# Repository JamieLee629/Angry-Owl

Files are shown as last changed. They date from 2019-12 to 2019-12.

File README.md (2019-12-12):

# Angry-Owl
ECE4180 Fall 2019 Final Project, Georgia Institute of Technology\
Project Members: Jamie Lee, Jingyi Yu

## Summary
A motion-detecting owl scarecrow controlled by a Raspberry Pi 3 Model B. Can move forwards and backwards, rotate, make scary sounds (optional), flap wings, and shine bright lights in the presence of live garden pests such as rodents and deer. The purpose is to scare away these pests which eat the leaves, fruits and vegetables of garden crops.

## Background Information
My dad maintains a large garden, but pests like raccoons and deer will often eat the fruits of his labor. He has tried store-bought deer repellent, but it did not work. It would be useful for gardeners if there was an infrared-detecting scarecrow that can move when it detects a sudden change in infrared radiation levels (i.e. an animal coming into view). Optionally, the scarecrow can make customizable sounds that can [scare the animals away](https://www.thestar.com/news/insight/2016/03/07/the-sound-that-strikes-fear-into-a-raccoons-heart.html). We decided to build our scarecrow in the form of an angry owl. The owl is a common predator among smaller pests, so the form of its silhouette alone can intimidate them. The loud commotion that the angry owl generates serves to scare off larger pests, such as deer and foxes.

## Electronics Parts List:
- 1x [Raspberry Pi 3 Model B](https://www.raspberrypi.org/products/raspberry-pi-3-model-b/)
- 1x mbed
- 1x Bare-Minimum RedBot Robot Kit
  - *The Bare-Minimum RedBot Robot Kit Contains:*
    - 1x [6" 3-Wire Cable](https://www.sparkfun.com/products/13164)
    - 1x [Pair of Wheels](https://www.sparkfun.com/products/13259)
    - 1x [Pair of 140-RPM Hobby Gearmotors](https://www.sparkfun.com/products/13302)
    - 1x [Shadow Chassis](https://www.sparkfun.com/products/13301)
    - 1x 4 AA Battery Pack and 5v barrel jack breadboard plug
- 2x [Super Bright White 5mm LED for eyes](https://www.adafruit.com/product/754)
- 3x [PIR Motion Sensors](https://www.adafruit.com/product/189)
- 1x [Pair of 140-RPM Hobby Gearmotors (for wing movement)](https://www.sparkfun.com/products/13302)
- 2x Dual-H Bridge Module
- 4x mini breadboards
### Parts for Optional Sound Feature
- 1x [PCB Mount Speaker](https://www.sparkfun.com/products/11089)
- 1x [Class-D Amplifier](https://os.mbed.com/components/TPA2005D1-Class-D-Audio-Amp/)
- 1x [SparkFun microSD Transflash Breakout](https://www.sparkfun.com/products/544)
- 1x [microSD Card - 16GB (Class 10)](https://www.sparkfun.com/products/15051)

## Structural Parts List
- An empty coffee can for the owl's body
- Cardboard for owl wings and face
- Access to drilling equipment

## Part 1 Instructions (Structural Set-up)
1. Assemble the bare-minimum RedBot Robot Kit by following [Step 2 (Motors and Wheels)](https://learn.sparkfun.com/tutorials/assembly-guide-for-redbot-with-shadow-chassis/2-motors-and-wheels) and [Step 5 (Chassis)](https://learn.sparkfun.com/tutorials/assembly-guide-for-redbot-with-shadow-chassis/5-chassis) in the [Assembly Guide for RedBot with Shadow Chassis](https://learn.sparkfun.com/tutorials/assembly-guide-for-redbot-with-shadow-chassis).
3. Drill three holes evenly spaced apart around the girth of the coffee can for the PIR Sensors.
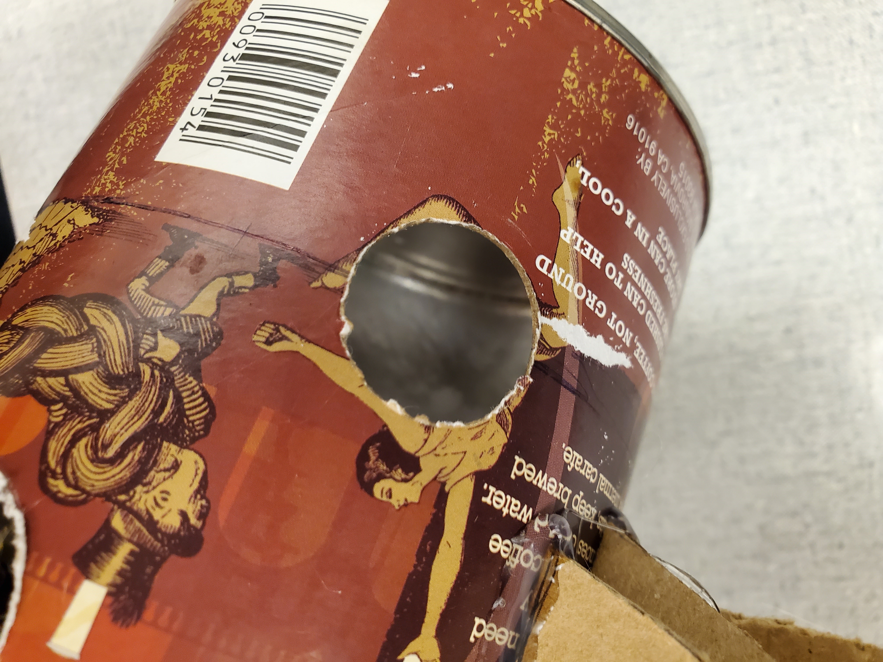
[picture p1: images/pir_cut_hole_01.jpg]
pir hole

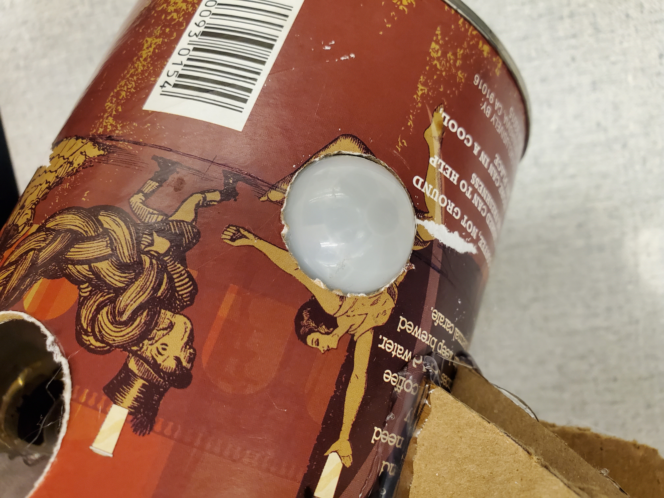
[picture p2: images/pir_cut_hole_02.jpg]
pir fits so snugly

4. [OPTIONAL] Drill a hole in the front and back to fit the speakers.
5. Drill two holes in the sides to fit the hobby gearmotors.
5. Add additional holes in the bottom of the can to accommodate the wires that will come from the RedBot's wheel motors.
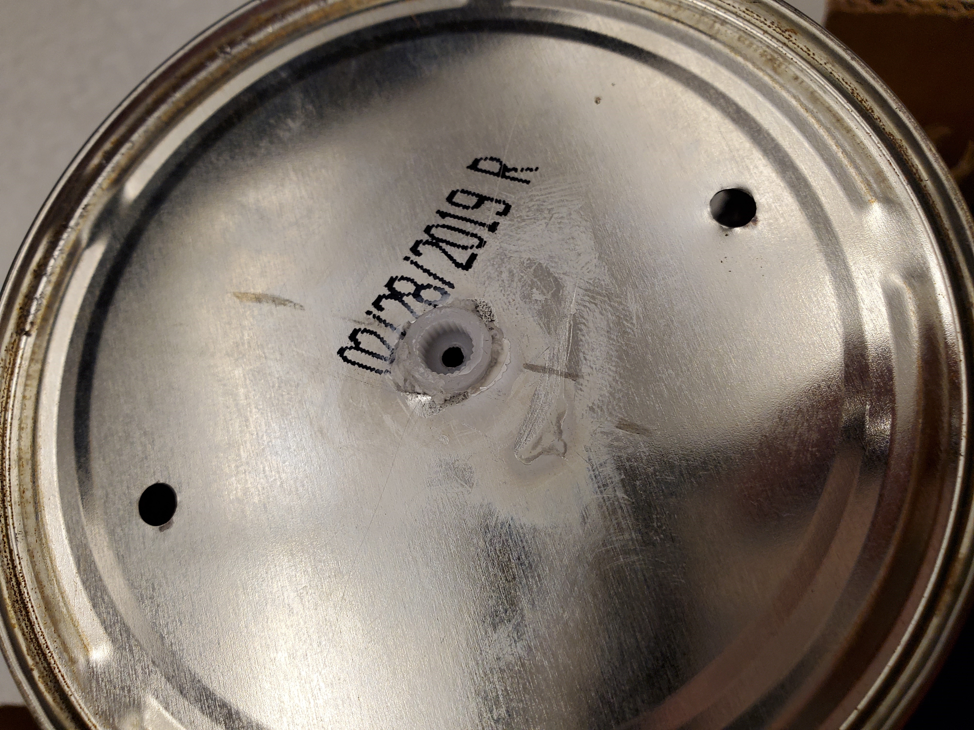
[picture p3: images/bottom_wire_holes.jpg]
bottom wire holes

6. Sketch and cut out 4 identical cardboard wings.
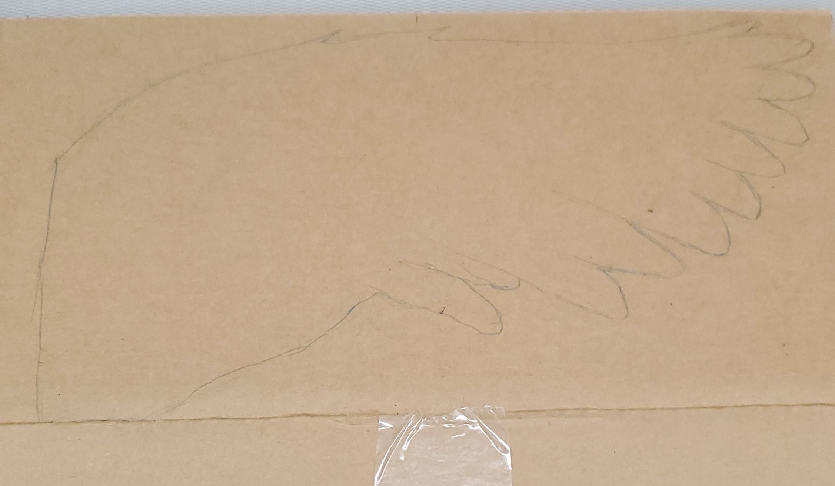
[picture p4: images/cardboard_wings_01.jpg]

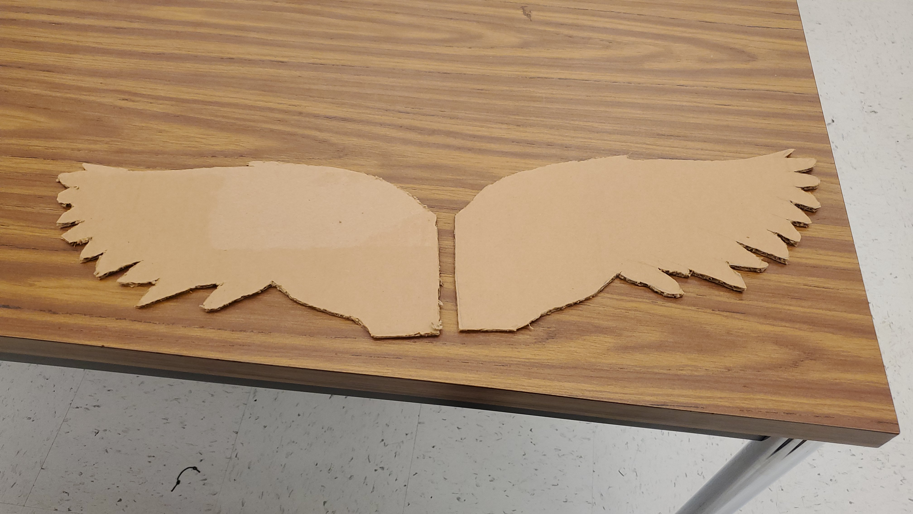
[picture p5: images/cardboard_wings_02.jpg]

7. Connect one pair of wheels to their motors and hot glue two wing cutouts to the wheels like in the images below. The 
end of the wing tips should be glued together at the opposite end of the wheel.
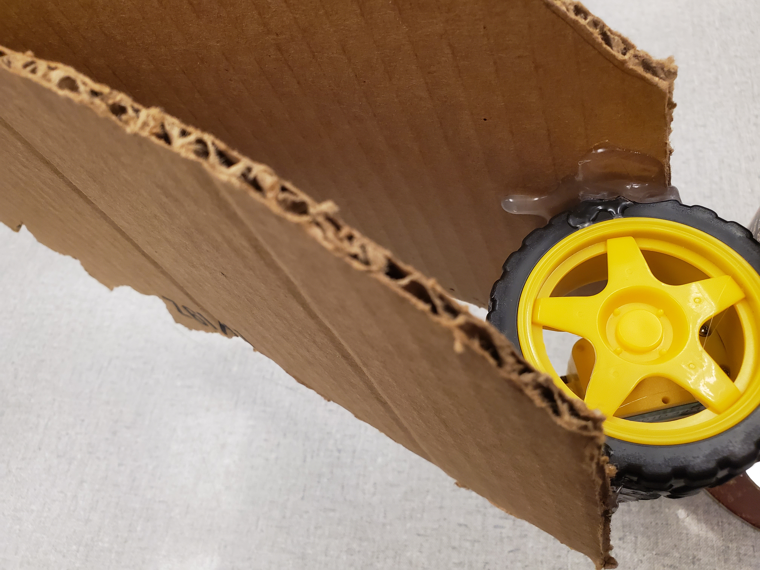
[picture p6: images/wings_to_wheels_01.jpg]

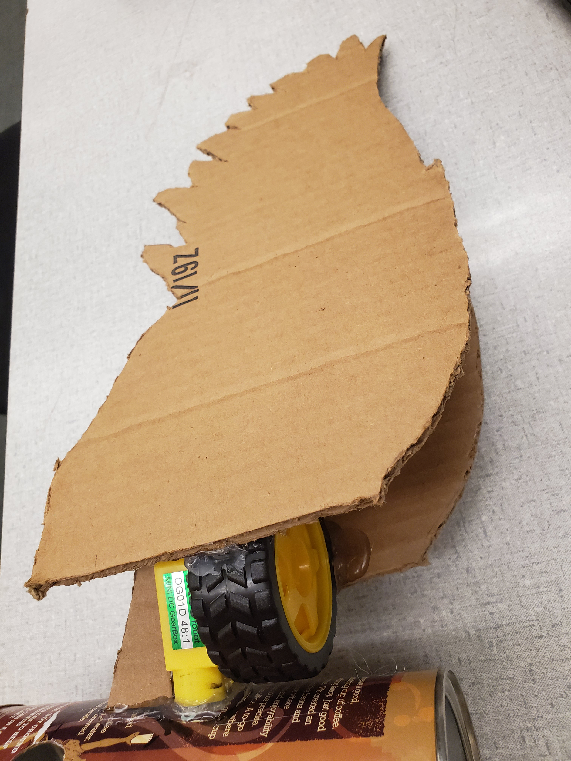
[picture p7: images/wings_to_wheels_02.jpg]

8. Hot glue the motors into place of their designated holes in the coffee can. Hot gluing the motors from the inside can
help with stability. Hot glue triangle-shaped cardboard support structures underneath each wing motor.
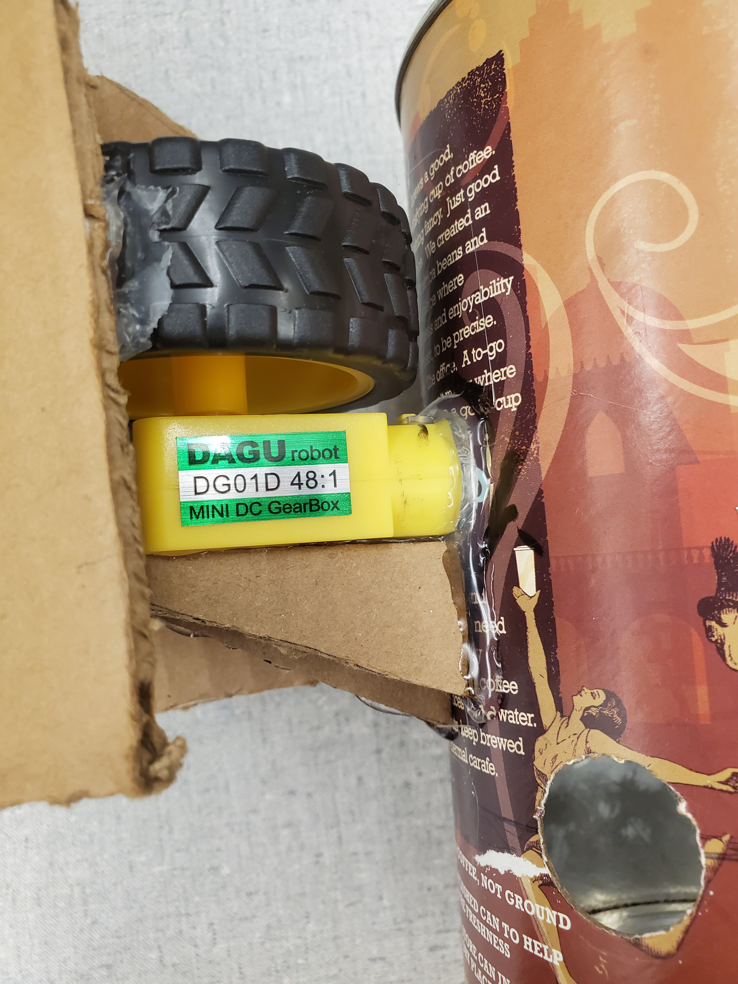
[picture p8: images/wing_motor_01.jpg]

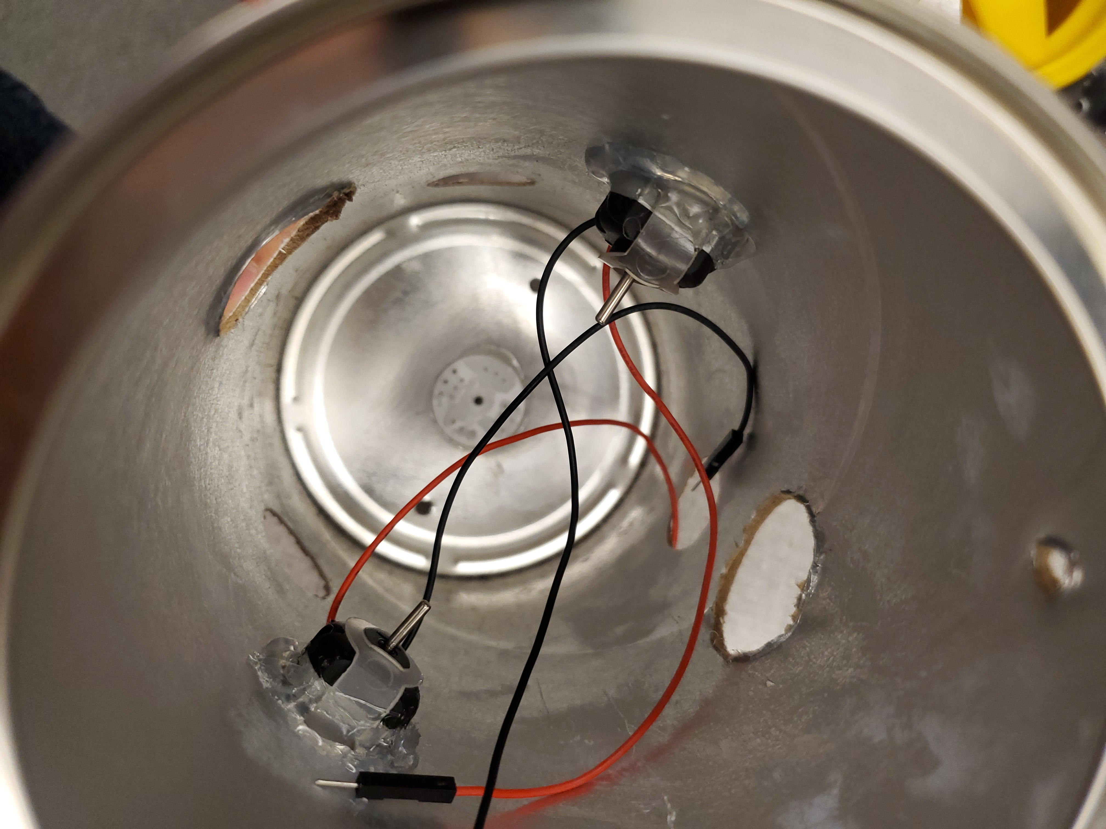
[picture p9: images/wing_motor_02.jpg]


## Part 2 Instructions: Hardware Overview
1. Wire the motors
2.[OPTIONAL] [Wire up the speakers and Class-D amplifier.](speaker-setup.md)
3. Follow the schematic below for guidance on wiring the other parts:
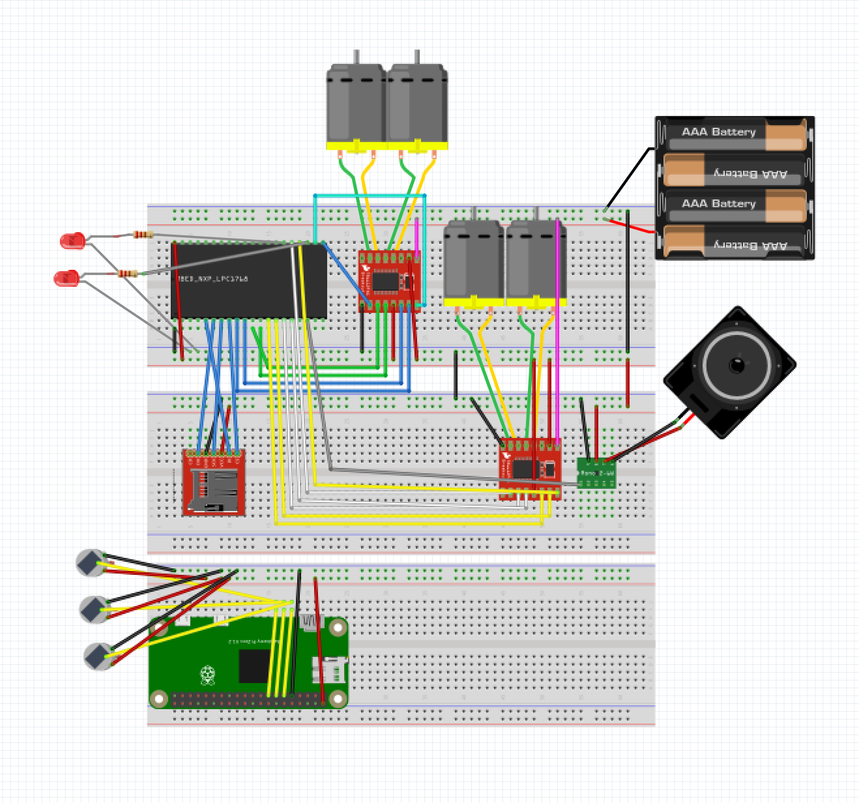
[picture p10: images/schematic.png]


Once the parts are wired, write the software (see Software Overview section) and load the code onto the mbed and pi. Once 
the hardware and software components are completed, place the mini-breadboards 
into the coffee can.

## Part 3 Instructions: Software Overview
### mbed code
```c++
#include "Servo.h"
#include "mbed.h"
#include "motordriver.h"
#include "rtos.h"
#include "stdio.h"
#include "SDFileSystem.h"
#include "wave_player.h"

volatile bool alarm  = false;

DigitalOut led1(LED1);
DigitalOut led2(LED2);
DigitalOut led3(LED3);
DigitalOut led4(LED4);

Ticker wing;
Ticker bark;

RawSerial pi(USBTX, USBRX);
Servo myservo(p23);      
Motor wingL(p22, p9, p10, 1); // pwm, fwd, rev
Motor wingR(p21, p12, p11, 1);//wings move in opposite directions
//reverse one motor's leads when wiring
Motor wheelL(p24, p14, p13, 1);
Motor wheelR(p25, p16, p15, 1);//wheels move in the same direction
PwmOut led1(p23);
PwmOut led2(p26);
AnalogIn flag(p20);

SDFileSystem sd(p5, p6, p7, p8, "sd");
AnalogOut DACout(p18);
wave_player waver(&DACout);
Mutex spk_mutex;
Mutex servo_mutex;
Mutex wing_mutex;
Mutex alrm_mutex;
char temp;

void startMotors() {
    for (float s= -1.0; s < 1.0 ; s += 0.002) 
        {
            wingL.speed(s);
            wingR.speed(s);
            wait(0.0005);
        }

    for (float x = -1.0; x< 1.0; x += 0.1)
        {
            wheelL.speed(x);
            wheelR.speed(x);
            wait(0.2);
        }
}

void stopMotors() {
    wingL.speed(0);
    wingL.speed(0);
    
    wheelL.speed(0);
    wheelR.speed(0);
}

void startSound() {
    FILE *wave_file;
    wave_file=fopen("/sd/sound00.wav","r");
    waver.play(wave_file);
    fclose(wave_file);
}

void piDetectInvader()
{
    while(true)
    {
        while(pi.readable())
        {
            temp = pi.getc();
            pi.putc(temp);
            
            if(temp == '1') { 
                alarm = true;
                led1=1;
                led2=1;
                startMotors();
                startSound();

            }
            if(temp == '0') {
                alarm = false;
                led1=0;
                led2=0;
                stopMotors();
            }
        }
    }
}

int main() 
{   
    pi.baud(9600);
    pi.attach(&piDetectInvader, Serial::RxIrq);

    while(true) { } 
}
```

### Raspberry PiZero code:
```c
/********************************************************************************************
*Filename      : pirsensor.c
*Description   : alarm system
*Author        : Alan
*Website       : www.osoyoo.com
*Update        : 2017/07/04

Edited: Jamie Lee and Jingyi Yu
Date: 12/09/2019
********************************************************************************************/
#include <wiringPi.h>
#include <stdio.h>
#include <stdlib.h>
#include <string.h>
#include <unistd.h>
#include <fcntl.h>
#include <errno.h>
#include <termios.h>

#define AlarmPin	        4 // GPIO 23
#define PIRPin0                 2 // GPIO 17
#define PIRPin1			1 // GPIO 18
#define PIRPin2 		3 // GPIO 22
#define alarmpin		5 // GPIO 24

// To compile, run in terminal: gcc -Wall -o pirsensor pirsensor.c -lwiringPi

int main(void)
{
	// When initialize wiring failed, print messageto screen
	if(wiringPiSetup() == -1){
		printf("setup wiringPi failed !");
		exit(1);
	}
	
	pinMode(AlarmPin, OUTPUT);
	pinMode(PIRPin0,INPUT);
	pinMode(PIRPin1, INPUT);
	pinMode(PIRPin2, INPUT);

	printf("\n");
	printf("========================================\n");
	printf("|              Alarm                   |\n");
	printf("|    ------------------------------    |\n");
	printf("|        PIR connect to GPIO0          |\n");
	printf("|                                      |\n");
	printf("|        Buzzer connect to GPIO1       |\n");
	printf("|                                      |\n");
	printf("|                                OSOYOO|\n");
	printf("========================================\n");
	printf("\n");
	
	// initalize connection to mbed
	int fd = -1;
	
	fd = open("/dev/ttyACM0", O_RDWR | O_NOCTTY | O_NDELAY);
	//open mbed's USB virtual com port
	if (fd == -1) {
		printf("open_port: Unable to open /dev/ttyACM - ");
		return -1;
	}
	// Turn off blocking for reads, use (fd, F_SETFL, FNDELAY) if you want that
        fcntl(fd, F_SETFL, 0);
	//Linux Raw serial setup options
	struct termios options; 
	tcgetattr(fd,&options);   //Get current serial settings in structure
	cfsetspeed(&options, B9600);   //Change a only few
	options.c_cflag &= ~CSTOPB;
	options.c_cflag |= CLOCAL;
	options.c_cflag |= CREAD;
	cfmakeraw(&options);
	tcsetattr(fd,TCSANOW,&options);    //Set serial to new settings
	sleep(1);
  
	int x, y, z;
	
	while(1){
	   if((x = digitalRead(PIRPin0)) || (y =digitalRead(PIRPin1)) || (z=digitalRead(PIRPin2))) {
		digitalWrite(AlarmPin, HIGH);
		printf("\n");
		printf("|       alarm...   |\n");
		
		if (x) {
			printf("PIRPin0 triggered.\n");
		} if (y) {
			printf("PIRPin1 triggered.\n");
		} if (z) {
			printf("PIRPin2 triggered.\n");
		}
		
		// Send signal to mbed when pir sensor is triggered
		write(fd,"1",1);        // on
		
		delay(1000);
		}
		else{
		digitalWrite(AlarmPin, LOW);
		printf("\n");
		printf("|   no alarm...    |\n");
		write(fd,"0",1);        // off
		delay(1000);
		}
	}
	// Don't forget to clean up and close the port
        tcdrain(fd);
        close(fd);
        return 0;
}
```

Suggested wav file sound clips:
- Dog bark (works best for raccoons)
- Gun Shot
- Hawk screech
- Fireworks

## Video Demo

### [Work in Progress #1](https://drive.google.com/open?id=154FSIQQ-LgN6EOjM2Z1NyNu87U1Fjonf)
### [Work in Progress #2](https://drive.google.com/open?id=157XXGBkYcu9aNBNSutsDD3ygir7XgGJG)
### [Final Product](https://drive.google.com/file/d/12H1Lxbc4HySWlYTQAr0e5FJRNjwTtKy5/view?usp=sharing)
### [Optional Sound Feature (A Barking Owl!)](https://drive.google.com/open?id=15P6EhN3GX4rHE0fRo2KBVwWmqkjTYG7r)

**Warning** In our experience, the wave_player and SDFileSystem libraries on Mbed 2.0 were not very RTOS-friendly 
when combined with Raspberry PiZero. If sound is to be implemented, the PIR sensor inputs should be received directly
from the mbed. You have been warned.

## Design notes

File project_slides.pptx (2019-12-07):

## Angry-Owl

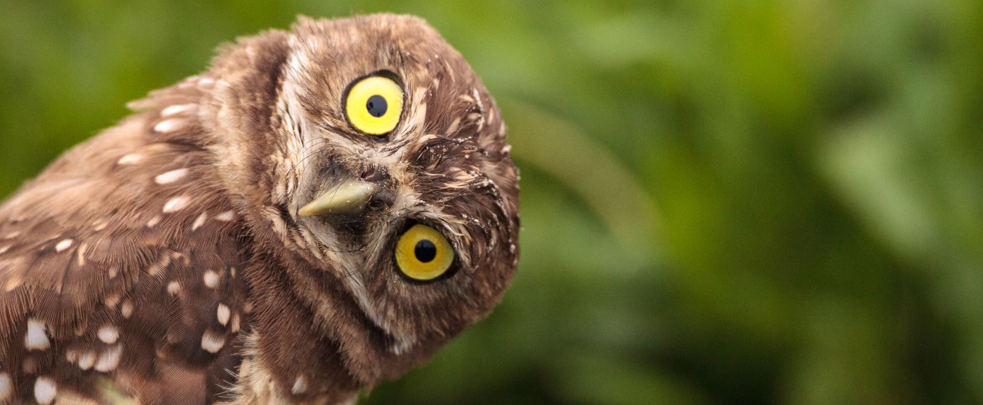
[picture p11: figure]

Jamie Lee & Jingyi Yu
ECE 4180 – FALL 2019 – Final Project

## Project Description

- Angry-Owl can scare away pests from your garden!
  - Rats/mice
  - Deer
  - Raccoons
- An owl-shaped electronic scarecrow

## Parts List

- 1x MBed
- 1x Bare-Minimum RedBot Robot Kit
  - The Bare-Minimum RedBot Robot Kit Contains:
    - 1x 6" 3-Wire Cable (https://www.sparkfun.com/products/13164)
    - 1x Pair of Wheels (https://www.sparkfun.com/products/13259)
    - 1x Pair of 140-RPM Hobby Gearmotors (https://www.sparkfun.com/products/13302)
    - 1x Shadow Chassis (https://www.sparkfun.com/products/13301)
- 1x Speaker bonnet and Speakers (https://www.adafruit.com/product/3346)
- 2x Super Bright White 5mm LED for eyes (https://www.adafruit.com/product/754)
- 3x PIR Motion Sensors (https://www.adafruit.com/product/189)
- 1x HS-422 Servo (Clockwise, Stock Rotation) (https://www.servocity.com/hs-422-servo#258=24&259=25)
- 1x Pair of 140-RPM Hobby Gearmotors (for wing movement) (https://www.sparkfun.com/products/13302)
- 1x Dual-H Bridge Module

## Software Used

## Demo Video/Photo

## Summary of Results

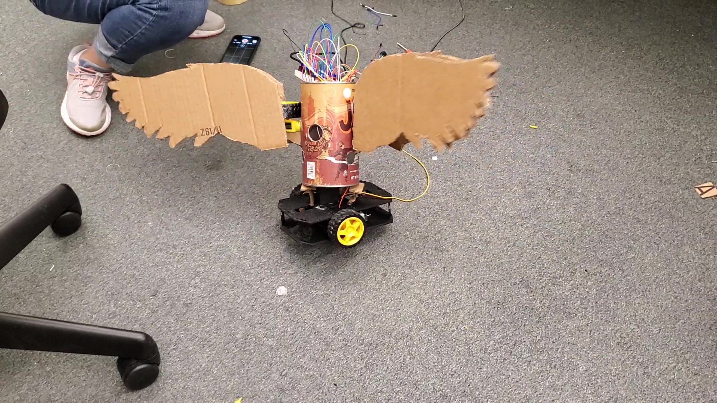
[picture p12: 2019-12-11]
images/wip_1_preview_image.jpg

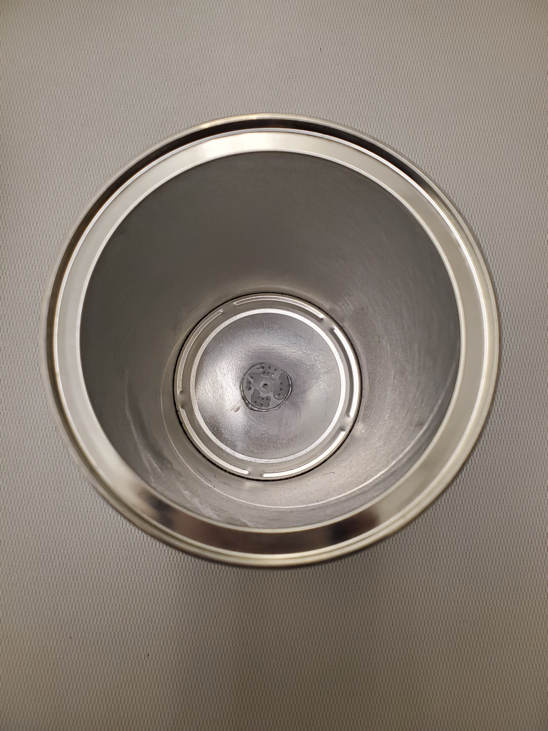
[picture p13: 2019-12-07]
images/servo_faceplate_01.jpg

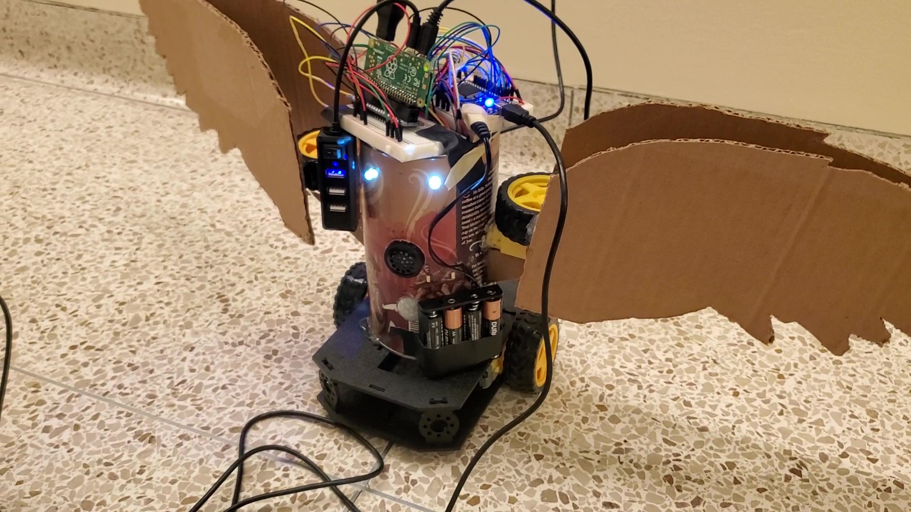
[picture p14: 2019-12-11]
images/wip_2_preview_image.jpg

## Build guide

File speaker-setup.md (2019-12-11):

# How to Set Up the MBed Speaker with Class-D Amp to Play WAV files

## Parts List
- mbed
- Speaker
- [Class-D Amp](https://os.mbed.com/components/TPA2005D1-Class-D-Audio-Amp/)
- [MicroSD Card Breakout Boards](https://www.sparkfun.com/products/544)
- SD Card

## Instructions
- Wire up the Speaker with the Class-D Amp to the mbed. For instructions on how to connect the Speaker and Class-D Amp, click 
[here](https://os.mbed.com/components/TPA2005D1-Class-D-Audio-Amp/) and scroll down to the Wiring section.
- Connect the MicroSD Card Breakout Board to the mbed. An example demo to get started with the microSD card can be found 
[here](https://os.mbed.com/cookbook/SD-Card-File-System).

### Wiring Instructions for MicroSD Breakout Board

| MicroSD Breakout | mbed |
|---|---|
| CS | 8 (DigitalOut cs) |
| DI | 5 (SPI mosi) |
| VCC | VOUT |
| SCK | 7 (SPI sclk) |
| GND | GND |
| DO | 6 (SPI miso) |
| CD | |
*** Warning
Note that VCC is 3.3V from mbed's VOUT pin. Do not use 5V from mbed's VU pin. 
5V power will damage the SD card. 
VOUT and VU are adjacent pins on some mbed platforms, 
so double check the jumper wire!

- Insert SD Card with desired `.WAV` files pre-loaded onto the card.
- Import the [.WAV player demo code](https://github.com/JamieLee629/Angry-Owl/tree/master/wav-player-demo-code) onto the
 online mbed compiler. Replace the file name with your `.WAV` file name. and compile. Load the bin file that results 
 from a successful compilation onto the mbed.
- Start the MBed and hear your sound play.

### Troubleshooting
If your sound comes out distorted and slow, try changing the spi frequency. In this project,
the spi frequency is set to 8 MHz.

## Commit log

2019-12-07 Adding images to readme instructions; Added powerpoint slides work in progress. Added speaker-setup write-up.
2019-12-09 adding schematics for hardware
    [angryOwlSche.fzz]
2019-12-09 Adding schematic screenshot (hardware).
2019-12-09 Adding hardware schematic image
